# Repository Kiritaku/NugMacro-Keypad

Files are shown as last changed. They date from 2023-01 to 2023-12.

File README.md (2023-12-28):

# NugMacro-Keypad
 This is my first (working)attempt at designing/assembling a keyboard from scratch.
 I'll try to include some issues I had, and how I resolved them for others to look at when troubleshooting their own designs, and for myself.
 
### Preface/Disclaimer
 For anyone reading this trying to troubleshoot their own project. If you have not realized this yet, especially if this is your first attemp at something like this, realize  that troubleshooting will be the most time consuming part of this. After all, it's always a learning experince, and thats just the nature of it.
- **Disclaimer** to anyone reading this. My understanding is that this project uses a bit of outdated components with the mcu, power connector, and daughterboard as theres definetely better MCU options and now better daughterboard options. I originally began this in 2020, so please don't use my schematic or parts list as a bible for building your own.

### Learning How To Use KiCAD
- The popular EDA of choice is [KiCAD](https://www.kicad.org/). It's free and not incredibly hard to learn. 
- YouTube videos worked best for me to get started.
- Going through KiCAD's doc page is incredibly helpful for any issues videos can't help you solve.
- Like with any new software, it's going to take a lot of time to really understand it, but try not to get discouraged.
 
### Schematic Issues
- Try to keep everything organized for yours, and others sake.
- Flags are your friend for organization.
- Try to look at it from the perspective of someone else every now and then. Noone wants to try to understand a shitty schematic, and if you take a long break from working on it, it's a pain in the ass to know what you were doing (Learned this the hard way).
- For footprints and symbols, there are some great libraries from people like [Ai03](https://github.com/ai03-2725) and [EBastler](https://github.com/ebastler). You can learn to make your own, but for your first attempt theres not a whole lot of reason to do that to yourself.
- When actually choosing your components, look at the datasheet for your chosen MCU. It's got everything you need to know for the basic requirements.

### PCB Issues
- If you already know how you want the outline of your PCB to look like, make sure your components will fit into this well to make it easy to route later.
- For USB connections, route your data lines in a close to equal length, with no other traces under or over them.
- Make your traces and layout look good. Your spending a lot of time to create this, and when you finally see the physical result, you want it to look intentional and thoughtful.
- Try to keep your crystal close to your MCU, and keep other traces away from it if they don't need to be there. A ground fill around it is also good for reducing possible interference.
- This took me longer to realize than it should have, but don't try to connect the ground net through a messy spiderweb of traces. Use a ground fill.
- Orient your MCU in whatever way makes it easist, and  prettiest, to route.

### Adding Artwork
- If you want, you can add drawings or other symbols/lettering to your silkscreen using something like [SVG to Shenzen](https://github.com/badgeek/svg2shenzhen).

### Manufacturing
- I ordered my boards from [JLCPCB](https://jlcpcb.com/).
- When making the production files, there are plugins for KiCAD that can make this easier, but just make sure you verify it looks correct.
- When selecting components for assmebly, make sure they are all correct. I had an issue from choosing a crystal at the correct speed, but wrong load.
- I used this formula **_(CL = (C1 * C2) / (C1 + C2) + Cstray)_** for finding what load rating I needed for my crystal. C1 and C2 are the caps for your crystal and I used **5pF** for my stray approximation.
- **For the love of god** do not try to assemble the entire board yourself thinking it wont be that hard.
- After you buy all the parts, ship everything, and assemble it. The time and money spent is not worth getting at least the majority of the board assembled form JLC.
- Especially if you try to do this all with a soldering iron, it can definetly be done, but there is a *__Lot__* of room for mistakes
- I did it thinking it would be good experince, and thinking it would be cool to do it all myself. It wasn't, mistakes are expensive, a lot can and did go wrong for me, and soldering experince will in no way make you immune to these mistakes.
- Given all of that, it is kinda fun doing it all yourself.
- And for components, I just uploaded my BOM to [DigiKey](https://www.digikey.com/) and ordered from them.
### Writing The Code
- I'll add info on this later, sorry.

### Case and Plate
- If you 3D print this yourself, make sure you have a well calibrated printer.
- I opted to use a piece of FR4 that I then lasercut to size.
- You can use a plate generator like this one from [swillkb](http://builder.swillkb.com/) to make it easier.
- I am currently working on a walnut case for my board, but when designing your case. Make sure you account for your desired mounting style, and daughterboard or any additional components you may have.

 ### Notes
 - I'll add some helpful links later.
 - I'll get these files organized a bit better/remove a good bit of junk soon.
 - Prob need to condense/organize this better.
 - If anyone has any questions about your own project or mine. Shoot me an email (Logan@Scootah.dev) and I'll do my best to give you a good answer.

 ### UPDATE
 Project is on hiatus for now, but if for whatever reason someone builds one of their own, qmk firmware is finished and if you want it just email me. 
 P.S. I wired the OLED wrong so prob wanna put it on the correct pins if you make your own to save a headache.

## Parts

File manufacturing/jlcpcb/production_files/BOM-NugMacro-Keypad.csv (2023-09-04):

Comment | Designator | Footprint | LCSC
#4b | MX14 | MXOnly-1U-NoLED
#1 | MX1 | MXOnly-1U-NoLED
#2c | MX7 | MXOnly-1U-NoLED
#4 | MX13 | MXOnly-1U-NoLED
#2d | MX8 | MXOnly-1U-NoLED
#3b | MX10 | MXOnly-1U-NoLED
#1b | MX2 | MXOnly-1U-NoLED
#3d | MX12 | MXOnly-1U-NoLED
#3c | MX11 | MXOnly-1U-NoLED
RotaryEncoder_Switch | SW2 | RotaryEncoder_Alps_EC11E-Switch_Vertical_H20mm
#4c | MX15 | MXOnly-2U-NoLED
#1c | MX3 | MXOnly-1U-NoLED
#1d | MX4 | MXOnly-1U-NoLED
Conn_01x04_Female_For_LCD | J3 | PinHeader_1x04_P2.54mm_Vertical
#2b | MX6 | MXOnly-1U-NoLED
#2 | MX5 | MXOnly-1U-NoLED
#3 | MX9 | MXOnly-1U-NoLED
22 | R3 | R_0805_2012Metric
D_Small | D3 | D_SOD-123
D_Small | D4 | D_SOD-123
0.1uF | C4 | C_0805_2012Metric
D_Small | D8 | D_SOD-123
ATmega32U4-A | U1 | TQFP-44_10x10mm_P0.8mm
10k | R4 | R_0805_2012Metric
22 | R2 | R_0805_2012Metric
D_Small | D15 | D_SOD-123
D_Small | D16 | D_SOD-123
Conn_01x04 | J2 | JST-SR-4
0.1uF | C3 | C_0805_2012Metric
10K | R6 | R_0805_2012Metric
D_Small | D14 | D_SOD-123
D_Small | D10 | D_SOD-123
10k | R1 | R_0805_2012Metric
SW_Push | SW1 | SKQG-1155865
D_Small | D6 | D_SOD-123
22pF | C1 | C_0805_2012Metric
D_Small | D12 | D_SOD-123
16MHz | Y1 | Crystal_SMD_3225-4Pin_3.2x2.5mm
22pF | C2 | C_0805_2012Metric
D_Small | D9 | D_SOD-123
D_Small | D11 | D_SOD-123
D_Small | D5 | D_SOD-123
D_Small | D1 | D_SOD-123
1uF | C6 | C_0805_2012Metric
0.1uF | C8 | C_0805_2012Metric
D_Small | D2 | D_SOD-123
D_Small | D7 | D_SOD-123
10uF | C7 | C_0805_2012Metric
10K | R5 | R_0805_2012Metric
0.1uF | C5 | C_0805_2012Metric
D_Small | D13 | D_SOD-123

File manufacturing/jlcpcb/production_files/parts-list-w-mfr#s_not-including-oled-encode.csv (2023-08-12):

Index | Quantity | Part Number | Manufacturer Part Number | Description | Customer Reference | Available | Backorder | Unit Price | Extended Price USD
1 | 1 | ATMEGA32U4-AU-ND | ATMEGA32U4-AU | IC MCU 8BIT 32KB FLASH 44TQFP |  | 1 | 0 | 5.55000 | 5.55
2 | 10 | 311-22ARCT-ND | RC0805JR-0722RL | RES 22 OHM 5% 1/8W 0805 |  | 10 | 0 | 0.02200 | 0.22
3 | 10 | 1276-1003-1-ND | CL21B104KBCNNNC | CAP CER 0.1UF 50V X7R 0805 |  | 10 | 0 | 0.04400 | 0.44
4 | 1 | 455-1804-1-ND | SM04B-SRSS-TB(LF)(SN) | CONN HEADER SMD R/A 4POS 1MM |  | 1 | 0 | 0.59000 | 0.59
5 | 1 | 4809-SKQGADE010CT-ND | SKQGADE010 | SWITCH TACT SPST-NO .05A 12VDC |  | 1 | 0 | 0.62000 | 0.62
6 | 2 | 1276-6455-1-ND | CL21A106KOQNNNG | CAP CER 10UF 16V X5R 0805 |  | 2 | 0 | 0.10000 | 0.20
7 | 10 | 1276-1066-1-ND | CL21B105KAFNNNE | CAP CER 1UF 25V X7R 0805 |  | 10 | 0 | 0.06500 | 0.65
8 | 10 | 1276-2605-1-ND | CL21C220JB61PNC | CAP CER 22PF 50V C0G/NP0 0805 |  | 0 | 10 | 0.10500 | 1.05
9 | 20 | 1N4148WTPMSCT-ND | 1N4148W-TP | DIODE GEN PURP 100V 150MA SOD123 |  | 20 | 0 | 0.10600 | 2.12
10 | 10 | RG20P10.0KBCT-ND | RG2012P-103-B-T5 | RES SMD 10K OHM 0.1% 1/8W 0805 |  | 10 | 0 | 0.26100 | 2.61
11 | 1 | 478-CX3225SB16000D0GZJC1CT-ND | CX3225SB16000D0GZJC1 | CRYSTAL 16.0000MHZ 8PF SMD |  | 1 | 0 | 0.61000 | 0.61

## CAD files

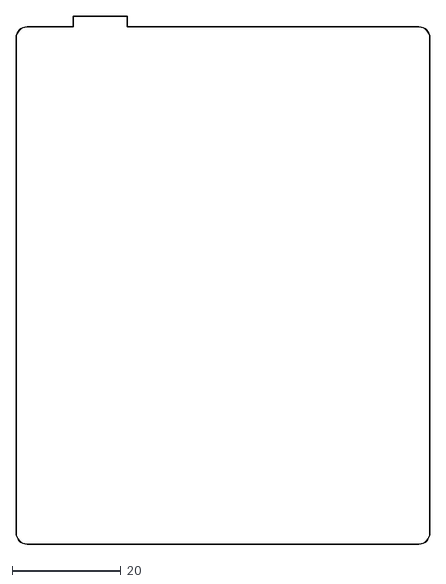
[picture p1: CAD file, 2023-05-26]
manufacturing/DXFs/Rev_2_Full_Blank_Rev3.dxf
76.2 x 97.2

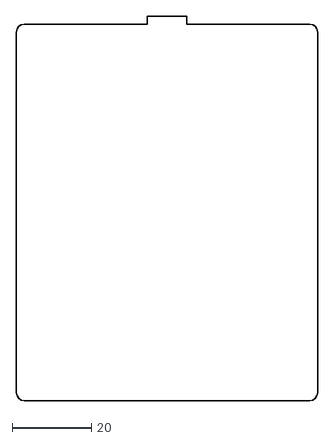
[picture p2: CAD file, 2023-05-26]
manufacturing/DXFs/Rev_2_Full_Blank.dxf
76.2 x 97.2

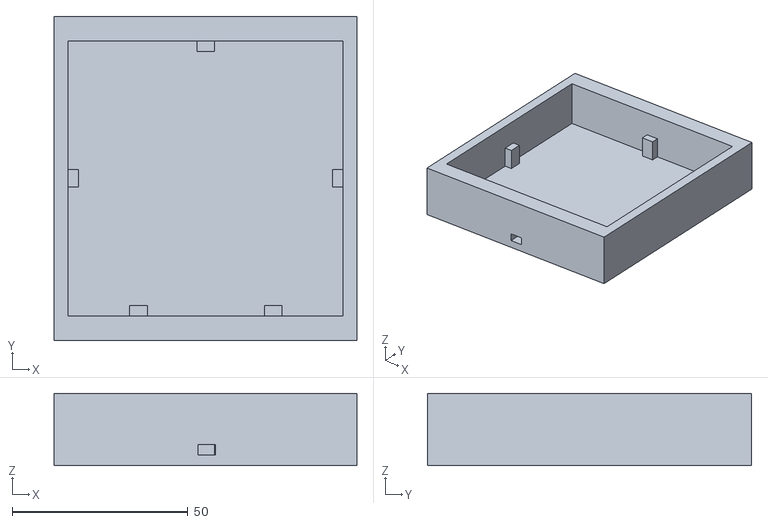
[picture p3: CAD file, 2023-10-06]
Case print test_.stl
86.2 x 92.2 x 20.6

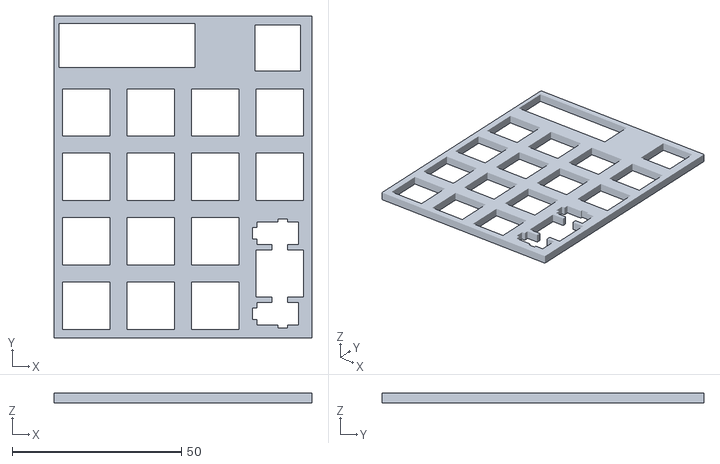
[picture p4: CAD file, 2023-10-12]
manufacturing/NugMacro-Plate/Plate wiht top fifth test 1 v3.stl
76.2 x 95.2 x 3.00

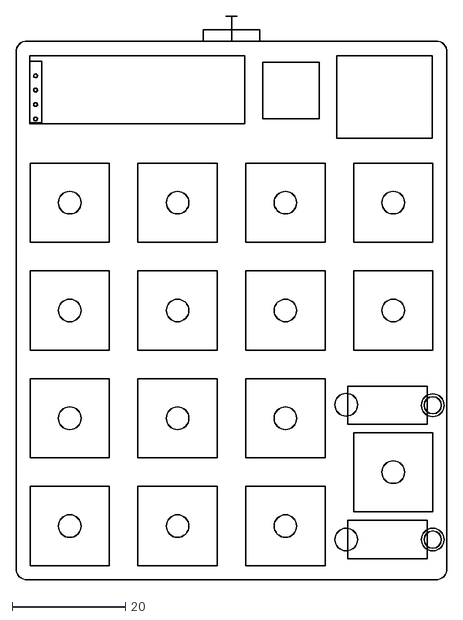
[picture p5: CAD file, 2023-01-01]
manufacturing/DXFs/Rev_2_Blank.dxf
76.2 x 99.6

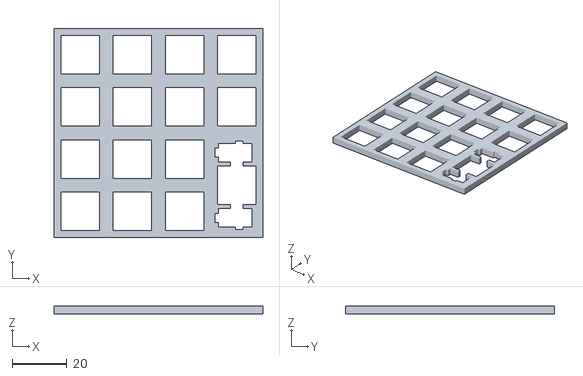
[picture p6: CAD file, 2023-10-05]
manufacturing/NugMacro-Plate/Plate minus top fifth v1.stl
76.2 x 76.2 x 3.00

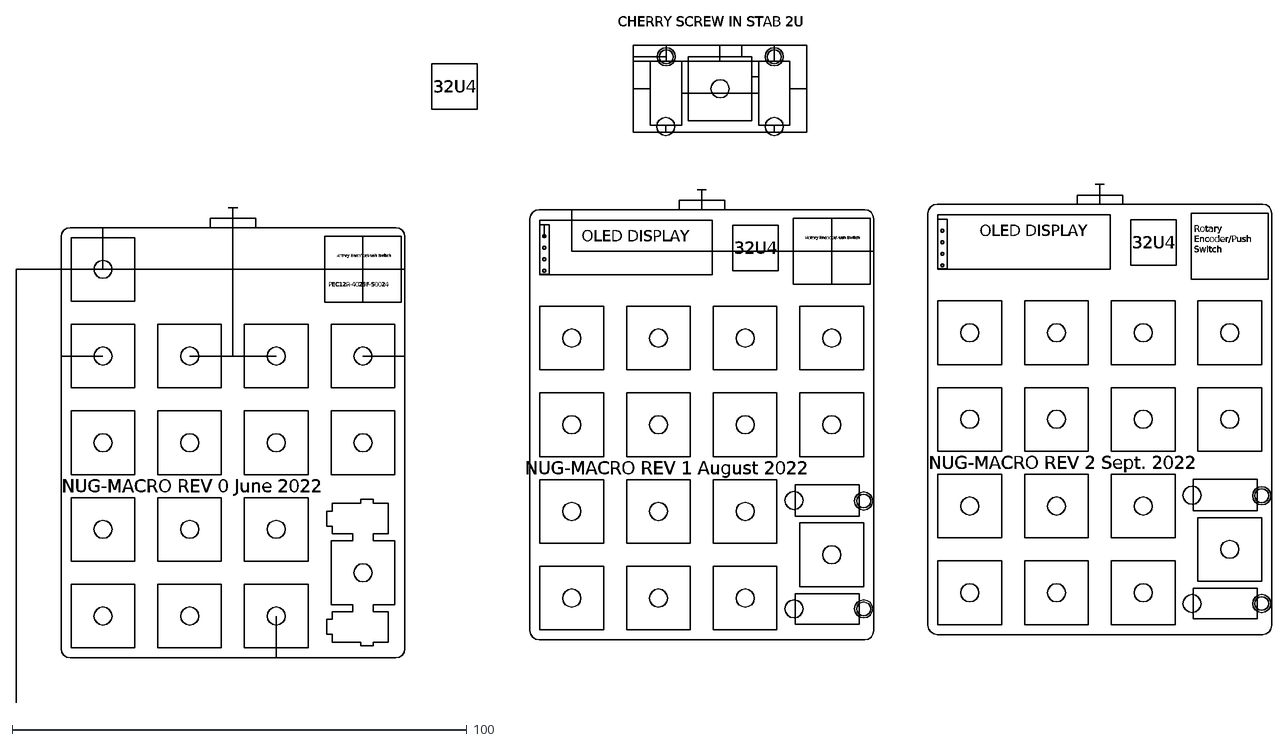
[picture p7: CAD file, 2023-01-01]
manufacturing/DXFs/Nug_Macro_0-2.dxf
NUG-MACRO REV 0 June 2022
Rotary Encoder/Push Switch
PEC12R-4025F-S0024
NUG-MACRO REV 1 August 2022
OLED DISPLAY
CHERRY SCREW IN STAB 2U
32U4
NUG-MACRO REV 2 Sept. 2022

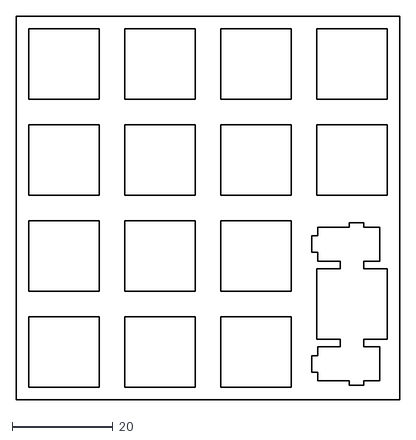
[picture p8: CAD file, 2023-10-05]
manufacturing/NugMacro-Plate/Plate minus top fifth.dxf
76.2 x 76.2

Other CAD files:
manufacturing/DXFs/Nug_Macro_Rev2_MaybeFinal.dxf
manufacturing/NugMacro-Plate/Plate wiht top fifth test 1 v1.stl

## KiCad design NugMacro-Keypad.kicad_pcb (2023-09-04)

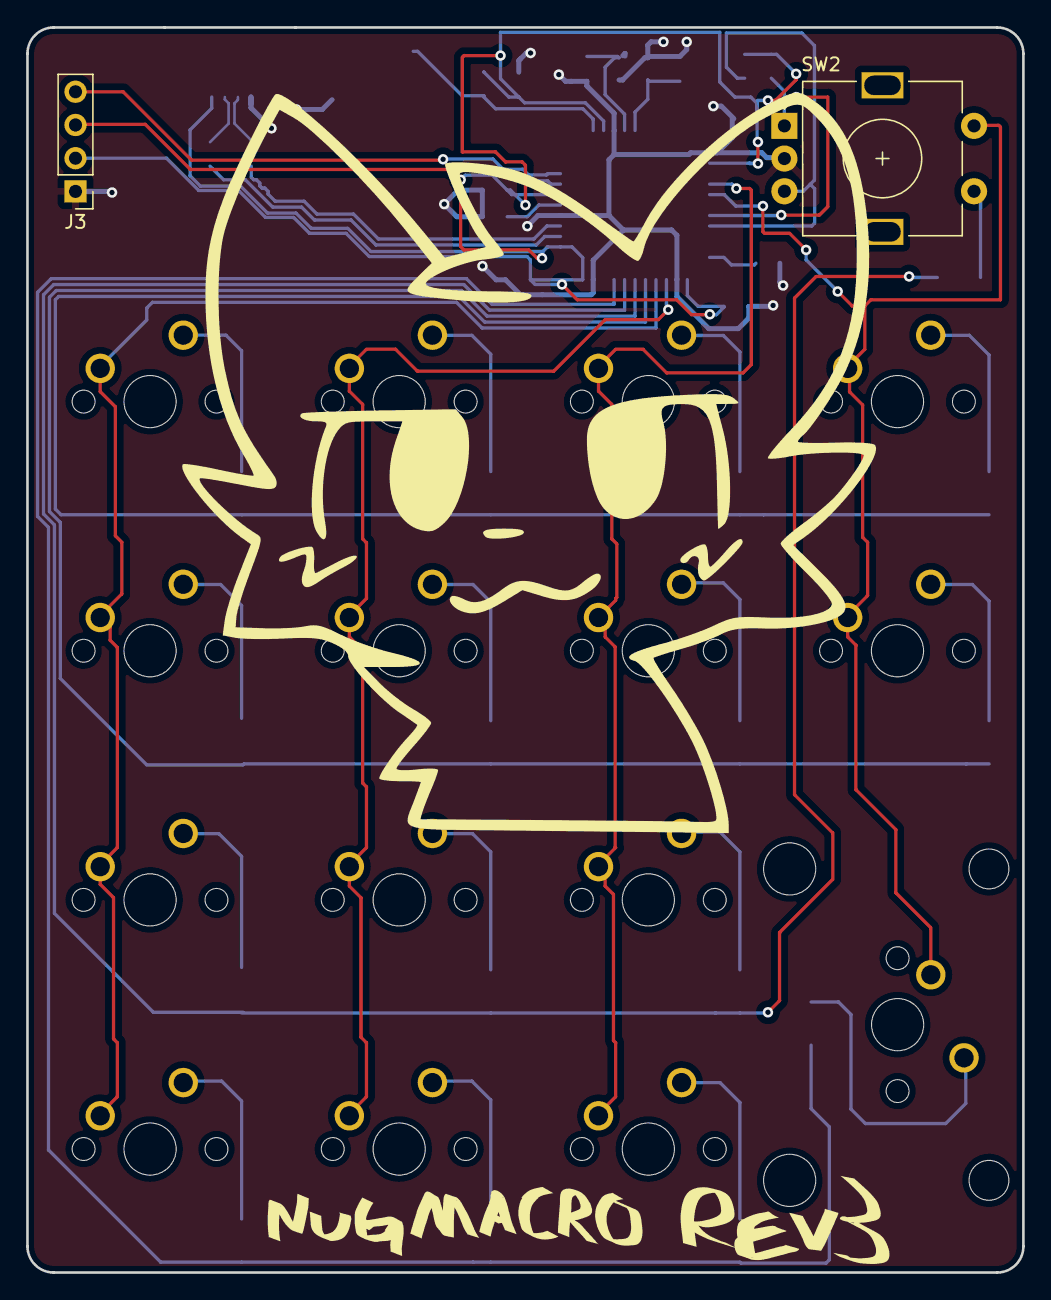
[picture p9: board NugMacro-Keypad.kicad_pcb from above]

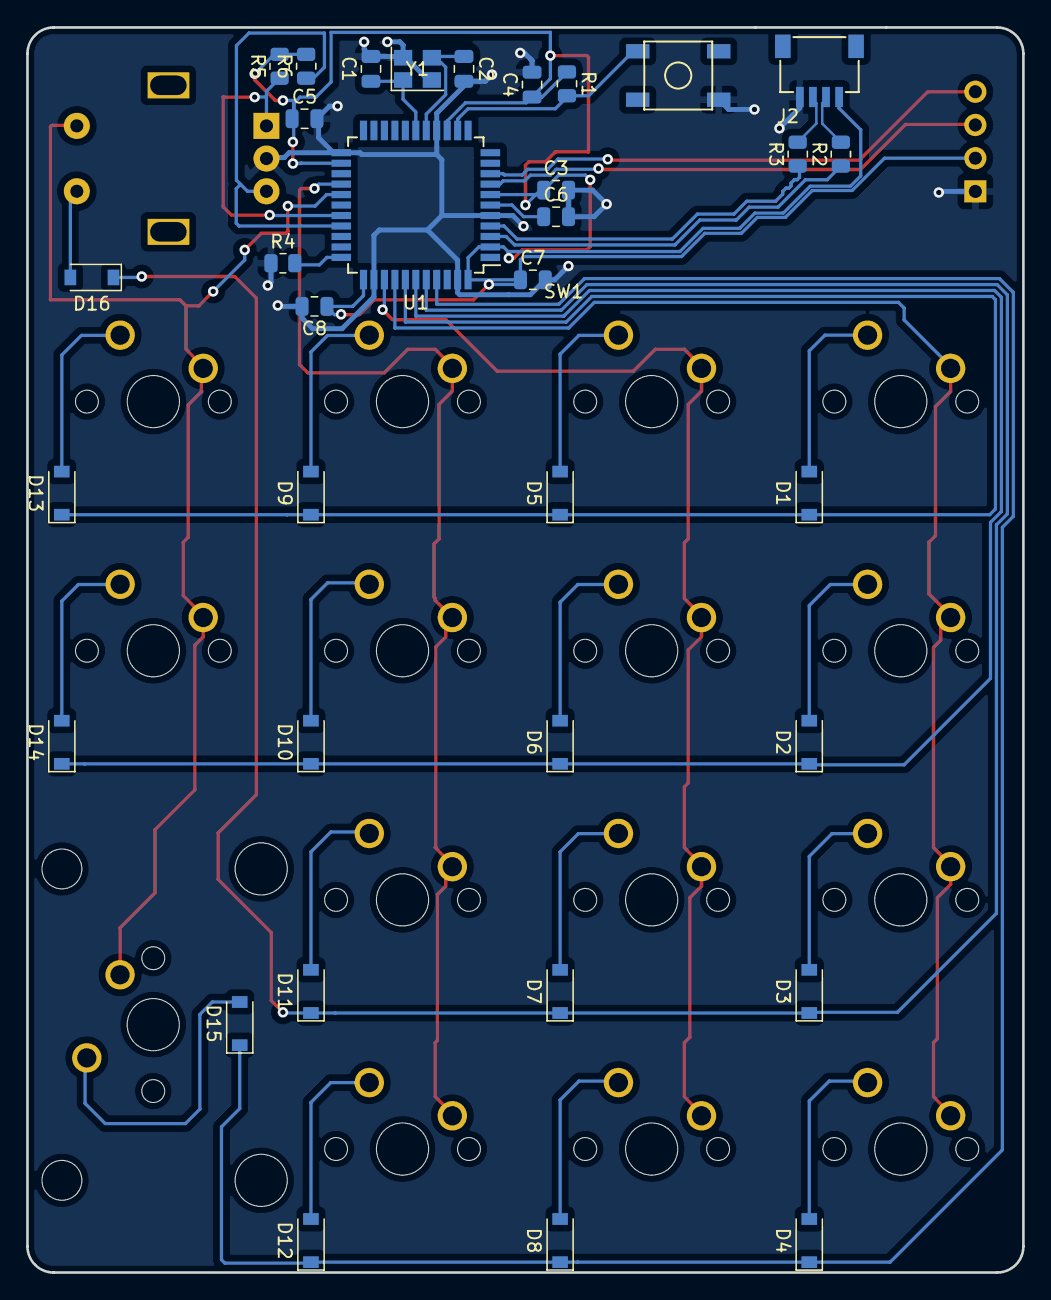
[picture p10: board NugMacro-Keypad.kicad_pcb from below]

Board: 2 copper layers, 76.2 x 95.2 mm, 51 parts (34 on the bottom side), 39 nets.

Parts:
C1, C2: 22pF; C_0805_2012Metric
C3, C4, C5, C8: 0.1uF; C_0805_2012Metric
C6: 1uF; C_0805_2012Metric
C7: 10uF; C_0805_2012Metric
D1, D2, D3, D4, D5, D6, D7, D8, D9, D10, D11, D12, D13, D14, D15, D16: D_Small; D_SOD-123
J2: Conn_01x04; JST-SR-4
J3: Conn_01x04_Female_For_LCD; PinHeader_1x04_P2.54mm_Vertical
MX1: #1; MXOnly-1U-NoLED
MX2: #1b; MXOnly-1U-NoLED
MX3: #1c; MXOnly-1U-NoLED
MX4: #1d; MXOnly-1U-NoLED
MX5: #2; MXOnly-1U-NoLED
MX6: #2b; MXOnly-1U-NoLED
MX7: #2c; MXOnly-1U-NoLED
MX8: #2d; MXOnly-1U-NoLED
MX9: #3; MXOnly-1U-NoLED
MX10: #3b; MXOnly-1U-NoLED
MX11: #3c; MXOnly-1U-NoLED
MX12: #3d; MXOnly-1U-NoLED
MX13: #4; MXOnly-1U-NoLED
MX14: #4b; MXOnly-1U-NoLED
MX15: #4c; MXOnly-2U-NoLED
R1, R4: 10k; R_0805_2012Metric
R2, R3: 22; R_0805_2012Metric
R5, R6: 10K; R_0805_2012Metric
SW1: SW_Push; SKQG-1155865
SW2: RotaryEncoder_Switch; RotaryEncoder_Alps_EC11E-Switch_Vertical_H20mm
U1: ATmega32U4-A; TQFP-44_10x10mm_P0.8mm
Y1: 16MHz; Crystal_SMD_3225-4Pin_3.2x2.5mm

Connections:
+5V: C3.1, C4.1, C5.1, C7.1, C8.1, J2.1, J3.2, R1.1, R5.2, R6.2, U1.2 (UVCC), U1.7 (VBUS), U1.14 (VCC), U1.24 (AVCC), U1.34 (VCC), U1.44 (AVCC)
CLK: R5.1, SW2.A, U1.29 (PB5)
COL0: MX1.1 (COL), MX2.1 (COL), MX3.1 (COL), MX4.1 (COL), U1.37 (PF6)
COL1: MX5.1 (COL), MX6.1 (COL), MX7.1 (COL), MX8.1 (COL), U1.36 (PF7)
COL2: MX9.1 (COL), MX10.1 (COL), MX11.1 (COL), MX12.1 (COL), U1.26 (PD6)
COL3: MX13.1 (COL), MX14.1 (COL), MX15.1 (COL), SW2.S2, U1.27 (PD7)
D+: J2.3, R3.2
D-: J2.2, R2.2
DT: R6.1, SW2.B, U1.30 (PB6)
GND: C1.2, C2.2, C3.2, C4.2, C5.2, C6.2, C7.2, C8.2, J2.4, J3.1, R4.1, SW1.1, SW2.C, U1.5 (UGND), U1.15 (GND), U1.23 (GND), U1.35 (GND), U1.43 (GND), Y1.2, Y1.4
unnamed: C6.1, U1.6 (UCAP)
unnamed: D1.2 (A), MX1.2 (ROW)
unnamed: D2.2 (A), MX2.2 (ROW)
unnamed: D3.2 (A), MX3.2 (ROW)
unnamed: D4.2 (A), MX4.2 (ROW)
unnamed: D5.2 (A), MX5.2 (ROW)
unnamed: D6.2 (A), MX6.2 (ROW)
unnamed: D7.2 (A), MX7.2 (ROW)
unnamed: D8.2 (A), MX8.2 (ROW)
unnamed: D9.2 (A), MX9.2 (ROW)
unnamed: D10.2 (A), MX10.2 (ROW)
unnamed: D11.2 (A), MX11.2 (ROW)
unnamed: D12.2 (A), MX12.2 (ROW)
unnamed: D13.2 (A), MX13.2 (ROW)
unnamed: D14.2 (A), MX14.2 (ROW)
unnamed: D15.2 (A), MX15.2 (ROW)
unnamed: D16.2 (A), SW2.S1
unnamed: R2.1, U1.3 (D-)
unnamed: R3.1, U1.4 (D+)
unnamed: R4.2, U1.33 (~HWB/PE2)
OLED1: J3.4, U1.9 (PB1)
OLED2: J3.3, U1.8 (PB0)
RESET: R1.2, SW1.2, U1.13 (~RESET)
ROW0: D1.1 (K), D5.1 (K), D9.1 (K), D13.1 (K), U1.38 (PF5)
ROW1: D2.1 (K), D6.1 (K), D10.1 (K), D14.1 (K), U1.39 (PF4)
ROW2: D3.1 (K), D7.1 (K), D11.1 (K), D16.1 (K), U1.40 (PF1)
ROW3: D4.1 (K), D8.1 (K), D12.1 (K), D15.1 (K), U1.41 (PF0)
XTAL1: C1.1, U1.17 (XTAL1), Y1.1
XTAL2: C2.1, U1.16 (XTAL2), Y1.3

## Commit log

2022-12-31 Initialize Project
    [NugMacro-Keypad.kicad_pcb, NugMacro-Keypad.kicad_sch]
2022-12-31 Wiring MCU
    [NugMacro-Keypad.kicad_sch]
2023-01-01 Board layout dxf's and usb-c footprints
    [Nug_Macro_0-2.dxf, Nug_Macro_Rev2_MaybeFinal.dxf, Rev_2_Blank.dxf]
2023-01-01 Reset circuit in schema
    [NugMacro-Keypad.kicad_sch]
2023-05-24 fixed fucky wucky on mcu
    [NugMacro-Keypad.kicad_sch]
2023-05-25 added encoder and oled with matrix
2023-05-25 schema finished with footprints assigned
    [MX_Matrix.kicad_sch, NugMacro-Keypad.kicad_sch]
2023-05-26 fixed annotations and oled footprint
    [MX_Matrix.kicad_sch, NugMacro-Keypad.kicad_sch]
2023-05-26 components placed on pcb and cut line should be fixed, routing will be next
    [NugMacro-Keypad.kicad_pcb, Rev_2_Full_Blank.dxf]
2023-05-26 Rev3 board outline, usb placement in middle makes for tough routing so moved to left
    [Rev_2_Full_Blank_Rev3.dxf]
2023-05-27 lil schema and pcb changes
    flipped/ changed around smd components so it may be easier to route, got rid of reset pins for simplicity sake with small board
    [MX_Matrix.kicad_sch, NugMacro-Keypad.kicad_pcb, NugMacro-Keypad.kicad_sch]
2023-08-05 routing changes
    routed keyswitch matrix. Have not done supporting components yet.
    [NugMacro-Keypad.kicad_pcb]
2023-08-05 routing changes again
    finished some routing going to change column/row flags hopefully works heres this if it dont.
    [NugMacro-Keypad.kicad_pcb]
2023-08-05 First prototype pcb done
    finally
    [NugMacro-Keypad.kicad_pcb, NugMacro-Keypad.kicad_sch]
2023-08-05 making gerber files
    idk
    [NugMacro-Keypad-B_Cu.gbr, NugMacro-Keypad-B_Mask.gbr, NugMacro-Keypad-B_Silkscreen.gbr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]
2023-08-06 finished pcb aside from silkscreen
    next update will be of silkscreen design but as of now pcb is ready for plotting.
    [NugMacro-Keypad-B_Cu.gbr, NugMacro-Keypad-B_Mask.gbr, NugMacro-Keypad-B_Silkscreen.gbr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]
2023-08-06 silkscreen art
    silkscreen stuf done
    [NugMacro-Keypad.kicad_pcb]
2023-08-06 production files done
    yayyyyyy
    [NugMacro-Keypad-B_Cu.gbl, NugMacro-Keypad-B_Cu.gbr, NugMacro-Keypad-B_Mask.gbr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]
2023-08-07 ssilkcreen changess
    added cat
    [NugMacro-Keypad.kicad_pcb]
2023-08-07 done for now time to order
    updated pcb grounds and silkscreen
    [BOM-NugMacro-Keypad.csv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]
2023-08-07 its done
    yay
    [MX_Matrix.kicad_sch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]
2023-08-12 starting rev 3 improvements
    now that i have a working prototype making small changes, changed switches to mx only, and cleaned up some routing so far.
    [MX_Matrix.kicad_sch, NugMacro-Keypad.kicad_pcb, NugMacro-Keypad.kicad_sch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]
2023-08-12 fixed zones and some routing
    might be done here for this project idk for sure yet. cant decide if i want to add anything else, but looks much better now.
    [NugMacro-Keypad.kicad_pcb]
2023-09-04 Second Version of Rev3 ig?
    fixed wiring on oled, made 1.5u key look a bit better, pulled back the jst connector to hopefully make compatible for a rubber o ring gasket mount.
    [NugMacro-Keypad.kicad_pcb, NugMacro-Keypad.kicad_sch]
2023-09-04 better? revision ordered
    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
    [BOM-NugMacro-Keypad.csv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]
2023-09-06 just double checked some possible design rule issues
    [NugMacro-Keypad.kicad_sch]
2023-10-05 Plate changes
    just gonna do plate in fusion now
    [NugMacro-Plate.kicad_pcb, NugMacro-Plate.kicad_sch, Plate minus top fifth.dxf]
2023-10-05 fusion plate test print
    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
    [Plate minus top fifth v1.stl]
2023-10-06 Create Case print test_.stl
    testing out a lil case design
    [Case print test_.stl]
2023-10-12 stuf
    idkl
    [Plate minus top fifth v1.stl]
2023-10-12 Create Plate wiht top fifth test 1 v1.stl
    testing plates
    [Plate wiht top fifth test 1 v1.stl]
2023-10-12 Create Plate wiht top fifth test 1 v3.stl
    [Plate wiht top fifth test 1 v3.stl]

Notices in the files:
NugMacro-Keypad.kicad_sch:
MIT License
